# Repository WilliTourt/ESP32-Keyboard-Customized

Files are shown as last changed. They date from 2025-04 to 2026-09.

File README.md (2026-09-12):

# ESP32 Keybrick

> Language: [English](README.md) | [简体中文](readme-zh-CN.md)

A multi-functional ESP32-C3 Bluetooth keyboard named **ESP32 Keybrick**. It provides five customizable mechanical keys and can send keystrokes, key combinations, and media-control commands to computers or other devices that support BLE HID.

This project uses the [Hid2Ble](https://github.com/BearLaboratory/Hid2Ble) library. Thanks to the project for making BLE HID functionality easier to implement.

ESP32 Keybrick internal

ESP32 Keybrick

## Features

- [√] Send a single key
- [√] Send key combinations
- [√] Send media-control keys
- [√] Countdown timer
- [√] Metronome
- [√] Switch between multiple key presets
- [√] Battery monitoring, low-battery notification, and BLE connection status indication
- [-] Create new key presets online without modifying the code
- [-] Automatic reconnection

Seven presets are currently built in:

1. `Ctrl XCVZ`: Ctrl+X, Ctrl+C, Ctrl+V, Ctrl+Z, Ctrl+Shift+Z
2. `Win Combos`: Alt+Tab, Win+D, Ctrl+Alt+Del, Win+Shift+S, empty
3. `VSCode`: Toggle comment, Tab, Shift+Tab, Quick Open, Command Palette
4. `LCEDA Tools`: Wire, Via, Copper, Top Copper, Bottom Copper
5. `SW Drawing`: Line, Circle, Rectangle, Smart Dimension, Normal To
6. `Tabs`: Five Tab keys
7. `MediaCtrls`: Brightness Down, Brightness Up, Volume Down, Volume Up, Play/Pause

To modify the presets, edit `KeyPreset presets[PRESET_COUNT]` in `ESP32-C3 BLE Keybrick/src/sys.cpp`. The code must currently be modified and recompiled; creating entirely new presets online is not supported.

You can refer to the existing presets when editing. For HID key values, consult the HID Usage Tables documentation available online.

You can modify `PRESET_COUNT` to increase or decrease the number of presets. The current number of presets is 7.

## Hardware

Main hardware:

- ESP32-C3-MINI-1 module
- 5 mechanical key switches
- 1 passive buzzer
- 1 status LED
- 0.91-inch 128×32 OLED display
- TP4056 lithium-battery charging module
- 3.7 V lithium battery

Pin definitions:

```cpp
#define ADC_PIN         A0
#define BUZZER_PIN      1
#define BTN_1_PIN       2
#define BTN_2_PIN       3
#define BTN_3_PIN       4
#define BTN_4_PIN       5
#define OLED_SDA        6
#define OLED_SCL        7
#define BTN_5_PIN       8
#define STATUS_LED      10
```

*The key inputs are currently configured as `INPUT` in `KEY_Init()`, so external pull-up resistors are required. If you do not have external pull-up resistors, change the input mode of all five keys to `INPUT_PULLUP` and verify the key-level logic according to your wiring.*

Schematic and PCB:

Schematic

PCB view

PCB view

## Build and Upload

1. Install [PlatformIO](https://platformio.org/) (the PlatformIO extension for VS Code is recommended).
2. Open the `ESP32-C3 BLE Keybrick` folder in PlatformIO.
3. Select the `esp32-c3-devkitm-1` environment.
4. Build and upload the program.

The project uses the Arduino framework. See `ESP32-C3 BLE Keybrick/platformio.ini` for the configuration.

## Usage

The default preset on first startup is `Ctrl XCVZ`:

| Key | Default function |
| --- | --- |
| BTN1 | Ctrl+X |
| BTN2 | Ctrl+C |
| BTN3 | Ctrl+V |
| BTN4 | Ctrl+Z |
| BTN5 | Ctrl+Shift+Z |

The device advertises over BLE as `ESP32C3 BLE Keybrick`. Search for and connect to it in the Bluetooth settings of your computer or other host.

### Mode switching

- Press and hold BTN4 to enter metronome mode.
- Press and hold BTN5 to enter countdown-timer setup mode. Press and hold BTN5 in countdown or any other function mode to return to normal mode.
- Press and hold BTN4 and BTN5 simultaneously to enter preset-selection mode.

### Countdown-timer setup

After entering countdown-timer setup mode:

- BTN1: Adjust hours
- BTN2: Adjust minutes
- BTN3: Enable/start the countdown
- BTN4: Reset
- BTN5: Return to normal mode

### Metronome setup

After entering metronome mode:

- BTN1: Decrease BPM
- BTN2: Increase BPM
- BTN3: Change the time signature
- BTN4: Start/stop the metronome

### Preset selection

After pressing and holding BTN4 and BTN5 simultaneously to enter preset-selection mode:

- BTN1: Select the previous preset
- BTN2: Select the next preset
- BTN3: Confirm and apply the current preset

After confirmation, the current preset is saved to the ESP32's on-chip EEPROM and will still be used after the device is restarted.

## Structure and Resources

- `ESP32-C3 BLE Keybrick/`: PlatformIO source-code folder
- `BOM_ESP32 Keybrick.xlsx`: Bill of materials
- `ESP32 BLE Keyboard v1.2f shell.stl`: Case model
- `ESP32 BLE Keyboard v1.2f cover.stl`: Case cover
- `ESP32-C3 BLE Keyboard v1.2.zip`: GERBER files

## Assembly Notes

- When soldering the OLED, do not insert it all the way. Inserting only part of the pad length is recommended; otherwise, the case and screen may interfere with each other.
- After soldering the mechanical key switches and OLED, cut the pins short to prevent them from protruding. The back of the PCB also needs to accommodate the TP4056 module and lithium battery.
- A 652272 lithium battery is recommended. Its thickness should not exceed approximately 5.5 mm so it can fit in the space between the case and PCB.
- The TP4056 module must be soldered directly to the pad area on the back of the PCB. It is recommended to solder the two pads on the input side first, then hold the module down with tweezers while soldering the remaining four pads.

## Known Issues

- ~~*An extra keystroke is sometimes triggered when returning to normal mode*~~ (fixed)
- ~~*Keys become unavailable when returning to normal mode from metronome mode*~~ (fixed)

## Credits

- Thanks to [BearLaboratory/Hid2Ble](https://github.com/BearLaboratory/Hid2Ble) for the BLE HID library.
- Thanks to WoodBreeze for helping with early testing :)

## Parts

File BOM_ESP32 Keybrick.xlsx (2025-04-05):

ID | Name | Designator | Footprint | Quantity | Manufacturer Part | Manufacturer | Supplier | Supplier Part
1 | Mechanical key shaft | K1,K2,K3,K4,K5 |  | 5
2 | 453K | R3 | R0603 | 1
3 | 100K | R4 | R0603 | 1
4 | 22uF | C1,C2 | C0603 | 2
5 | 2.2uH | L1 | IND-SMD_L3.0-W3.0_FNR30XXS | 1 | FNR3015S2R2MT | cjiang(长江微电) | LCSC | C167747
6 | TLV62568DBVR | U2 | SOT-23-5_L3.0-W1.7-P0.95-LS2.8-BR | 1 | TLV62568DBVR | TI(德州仪器) | LCSC | C163219
7 | ESP32-C3-MINI-1-N4 | U1 | WIFIM-SMD_ESP32-C3-MINI-1 | 1 | ESP32-C3-MINI-1-N4 | ESPRESSIF(乐鑫) | LCSC | C2838502
8 | Key_SMD_3x4x2 | 9,EN | Key_SMD_3x4x2 | 2
9 | 10K | R7,R8,R5,R6,R11,R12,R13,R17,R16 | R0603 | 9
10 | 10uF | C14 | C0603 | 1
11 | 100nF | C15,C17 | C0603 | 2
12 | 1uF | C13,C16 | C0603 | 2
13 | S9013 | Q1 | SOT-23-3_L2.9-W1.4-P1.90-LS2.6-BR | 1 | S9013 | CBI(创基) | LCSC | C2836092
14 | 2.7kHz | BUZ/1 | BUZ-TH_BD9.0-P4.00-D0.6-FD | 1 | QMB-09B-03 | 华能 | LCSC | C96256
15 | 1K | R10 | R0805 | 1
16 | LED_0603-G | LED/10 | LED_0603 | 1
17 | 1K | R9 | R0603 | 1
18 | TP4056模组 | TP4056 | TP4056模组 | 1
19 | 模组-OLED-0.91-12832-I2C-SSD1306 | OLED | MOULD-OLED-0.91-12832-I2C-SSD1306 | 1
20 | 20K | R14 | R0603 | 1
21 | 36K | R15 | R0603 | 1
22 | TA-3525-A1 | SW1 | SW-SMD_3P-L9.1-W3.5-P2.50_BDKG-3P-H2MM | 1 | TA-3525-A1 | Yuandi(元迪) | LCSC | C514018
23 | CH340C | U3 | SOP-16_L10.0-W3.9-P1.27-LS6.0-BL | 1 | CH340C | WCH(南京沁恒) | LCSC | C84681
24 | S8050 | Q3,Q2 | SOT-23-3_L2.9-W1.3-P1.90-LS2.3-BR | 2 | S8050 | 宏迦橙 | LCSC | C20069125
25 | Type-C-TOP_1 | USB1,USB2 | TYPE-C 16PIN-SMD | 2 |  |  | LCSC | C9900005857
26 | USBLC6-2SC6 | D1 | SOT-23-6_L2.9-W1.6-P0.95-LS2.8-BL | 1 | USBLC6-2SC6 | UMW(友台半导体) | LCSC | C2687116
27 | 5.1K | R1,R2,R18,R19 | R0603 | 4

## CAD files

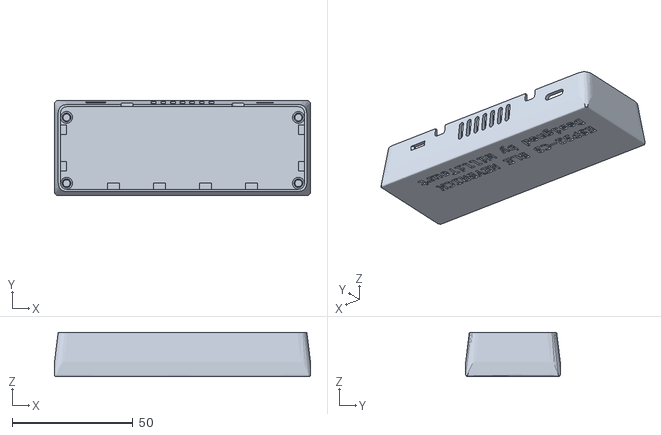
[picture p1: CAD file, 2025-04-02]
ESP32 BLE Keyboard v1.2f shell.stl
106.2 x 39.3 x 18.3

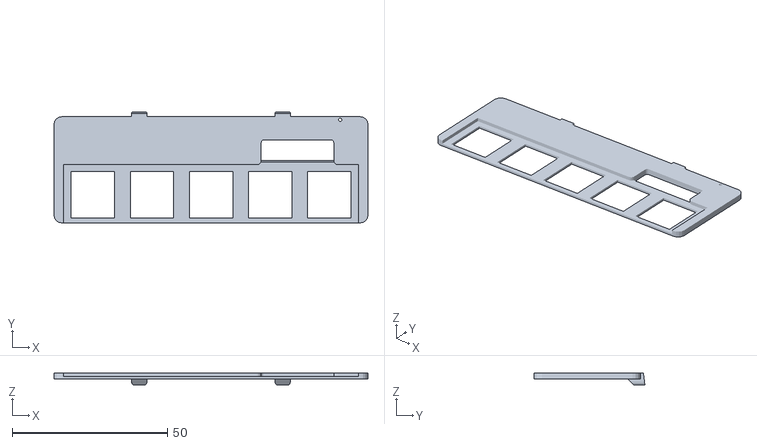
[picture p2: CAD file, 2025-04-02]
ESP32 BLE Keyboard v1.2f cover.stl
101.2 x 35.7 x 4.00

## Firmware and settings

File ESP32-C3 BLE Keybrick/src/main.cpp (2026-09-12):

/*******************************************************
 * ESP32-C3 BLE Keybrick v1.2
 * Copyright (c) 2025 WilliTourt 2944925833@qq.com
 * 
 * CHANGELOG: 
 * - 2025.03 V1.0   Initial release
 * 
 * - 2025.04 V1.1   Display bugfix, changed battery params
 * 
 * - 2026.09 V1.2   Improvements: - MediaCtrl preset now works!
 *                                - fixed display clear problem
 *                                - fixed spurious triggering when new key config enables or quitting alarm or metronome
*******************************************************/

#include <Arduino.h>
#include "Hid2Ble.h"

extern "C" {

#include "key.h"
#include "oled.h"
#include "battery.h"

}

#include "sys.h"
#include "def.h"
#include "timerMetronome.h"

#define SCREEN_ALMOST_TIMEOUT 20000
#define SCREEN_TIMEOUT 30000

void OLED_Update();
void OLED_ChkTimeout();
void KEY_Send();

Hid2Ble keybrick("ESP32C3 BLE Keybrick", "WilliTourt", 100);

/**
  * @brief  Determine whether should send key events to BLE HID device, and count down for timer. 10ms timer interrupt.
  * @param  None
  * @retval None
  */
void IRAM_ATTR KEY_Detect() {

    // Loop through each key to check its state and decide if a key event should be sent
    for (int i = 0; i < 5; i++) {
        if (keyState[i].isReleased) {
            // If the key was released, ensure it is not pressed and set the flag to send a release event
            if (!keyState[i].isPressed) {
                sendRelease = true;
                keyState[i].isReleased = false;
            }
        } else {
            // If the key is pressed, mark it as shouldSend to send the press event later
            if (keyState[i].isPressed) {
                keyState[i].shouldSend = true;
            }
        }
    }

    // Variable for timer count down (each second)
    static uint8_t timerCnt = 0;
    if (timer.enabled) {
        timerCnt++;
        if (timerCnt >= 100) {
            uint32_t now = millis();
            if (now >= (timer.targetSec - 1)) {
                timerTriggered = true;
                timer.enabled = false;
            }
            timerCnt = 0;
        }
    }

}

/**
  * @brief  Update battery level to BLE HID device. 1min timer interrupt.
  * @param  None
  * @retval None
  */
void IRAM_ATTR BLE_UpdateBAT() {
    if (keybrick.isConnected()) {
        keybrick.setBatteryLevel(BAT_GetPercentage());
    }
}

void setup() {

    // Initialize keys, load and apply system preset
    KEY_Init();
    SYS_LoadPreset();
    SYS_ApplyPreset(currentPreset);

    OLED_Init(7, 6, 32, 0);
    pinMode(STATUS_LED, OUTPUT);
    pinMode(BUZZER_PIN, OUTPUT);

    hw_timer_t* timer = timerBegin(0, 80, true);
    timerAttachInterrupt(timer, &KEY_Detect, true);
    timerAlarmWrite(timer, 10000, true);            // 10 ms
    timerAlarmEnable(timer);

    hw_timer_t* timer1 = timerBegin(1, 800, true);
    timerAttachInterrupt(timer1, &BLE_UpdateBAT, true);
    timerAlarmWrite(timer1, 6000000, true);         // 1 min
    timerAlarmEnable(timer1);

    keybrick.begin();
}

void loop() {
    // Update key states and handle mode switching
    active = KEY_Update();

    if (BAT_IS_LOW) {
        OLED_LowBrightness(true);
    }

    SYS_ModeSwitch();

    // Check BLE connection status and send key events if connected
    if (keybrick.isConnected()) {
        sysStatus.bleConnected = true;

        if (enableKey) {
            KEY_Send();
        }
    } else {
        sysStatus.bleConnected = false;
        // How to reconnect automatically?
    }

    // Handle different modes
    switch (currentMode) {  // Clear OLED display and send a release event if mode changed
        case MODE_NORMAL:
            if (!enableKey) { OLED_Clear(); keybrick.send2Ble(release); scrollPos = 0; }
            enableKey = true;
            TIMER_Display();
            break;
        case MODE_TIMER_SET:
            if (enableKey) { OLED_Clear(); keybrick.send2Ble(release); }
            enableKey = false;
            TIMER_Set();
            break;
        case MODE_METRONOME:
            if (enableKey) { OLED_Clear(); keybrick.send2Ble(release); }
            enableKey = false;
            METRONOME_Set();
            break;
        case MODE_KEY_CONFIG:
            if (enableKey) { OLED_Clear(); keybrick.send2Ble(release); scrollPos = 0; }
            enableKey = false;
            SYS_KeyConfig();
            break;
    }

    TIMER_Handle();
    METRONOME_Handle();
    BAT_Read();
    SYS_StatusLEDCtrl();
    OLED_ChkTimeout();
    OLED_Update();
}

/**
  * @brief  Send key events to BLE HID device
  * @param  None
  * @retval None
  */
void KEY_Send() {
    for (int i = 0; i < 5; i++) {
        if (keyState[i].shouldSend && !keyState[i].isReleased) {

            // Key 4/5 are also used for long-press mode switching. Wait until release
            if ((i == 3 || i == 4) && keyState[i].isPressed) {
                continue;
            }

            if (currentPreset == 6) { // MediaCtrls
                keybrick.sendMedia2Ble(media[i]);
            } else {
                switch (i) {
                    case 0: keybrick.send2Ble(k1Buf); break;
                    case 1: keybrick.send2Ble(k2Buf); break;
                    case 2: keybrick.send2Ble(k3Buf); break;
                    case 3: keybrick.send2Ble(k4Buf); break;
                    case 4: keybrick.send2Ble(k5Buf); break;
                }
            }
            keyState[i].isReleased = true;
            keyState[i].shouldSend = false;
        }
    }
    if (sendRelease) {
        if (currentPreset == 6) {
            keybrick.sendMedia2Ble(mediaRelease);
        } else {
            keybrick.send2Ble(release);
        }
        sendRelease = false;
    }
}

// Check if screen timeout has been reached and turn off OLED if necessary
void OLED_ChkTimeout() {
    static uint32_t lastCheck = 0;
    if (active) {
        if (!BAT_IS_LOW) { OLED_LowBrightness(false); }
        lastActivityTime = millis();
        if (!screenOn) {
            OLED_Power(true);
            screenOn = true;
        }
    }
    if (millis() - lastCheck > 1000) {
        if (screenOn && (millis() - lastActivityTime > SCREEN_ALMOST_TIMEOUT)) {
            OLED_LowBrightness(true);
        }
        if (screenOn && (millis() - lastActivityTime > SCREEN_TIMEOUT)) {
            OLED_Power(false);
            screenOn = false;
        }
        lastCheck = millis();
    }
}

// OLED information display & prompts
void OLED_Update() {

    if (!screenOn) { return; }

    switch (currentMode) {
        case MODE_NORMAL:
            OLED_PrintImage(0, 0, 128, 1, (uint8_t*)Title);
            OLED_PrintImage(2, 1, 8, 1, (uint8_t*)BT);
            if (sysStatus.bleConnected) {
                OLED_PrintText(10, 1, "Connected  ", 8);
            } else {
                OLED_PrintText(10, 1, "Unconnected", 8);
            }
            OLED_PrintImage(90, 1, 15, 1, (uint8_t*)Bat);
            OLED_PrintVar(100, 1, BAT_GetPercentage(), "int", 3);
            OLED_PrintText(118, 1, "%", 8);

            static uint32_t lastScroll = 0;
            if (scrollPos < 5) {
                // Padding the line with spaces overwrites the previous text without
                // clearing the display, which avoids visible flicker.
                char keydesc[22];
                snprintf(keydesc, sizeof(keydesc), "Key%d: %s", scrollPos + 1,
                         presets[currentPreset].keyDescription[scrollPos]);
                for (size_t i = strlen(keydesc); i < 21; i++) {
                    keydesc[i] = ' ';
                }
                keydesc[21] = '\0';
                OLED_PrintText(0, 2, keydesc, 8);
            }
            if (millis() - lastScroll > 2000) {
                scrollPos = (scrollPos + 1) % 5;
                lastScroll = millis();
            }
            break;
        case MODE_TIMER_SET:
            OLED_PrintText(0, 0, "> Timer Settings", 8);
            char timeStr[16];
            sprintf(timeStr, " <%02d:%02d>", timer.hours, timer.minutes);
            OLED_PrintText(0, 1, timeStr, 16);
            if (timer.enabled) {
                char timeEn[10];
                uint32_t remainingSec = (timer.targetSec - millis()) / 1000;
                sprintf(timeEn, "%02d:%02d[ON]", remainingSec / 3600, (remainingSec % 3600) / 60);
                OLED_PrintText(72, 1, timeEn, 8);
            } else {
                OLED_ClearPart(72, 1, 128, 2);
            }
            OLED_PrintText(72, 2, "Cnt Down", 8);
            OLED_PrintText(0, 3, "1|HH 2|MM 3|En 4|Rst", 8);
            break;
        case MODE_METRONOME:
            OLED_PrintText(0, 0, "> Metronome", 8);
            char infoStr[32];
            sprintf(infoStr, "BPM:%03d SIG:%d/4", metro.bpm, metro.timeSig);
            OLED_PrintText(0, 1, infoStr, 16);
            OLED_PrintText(0, 3, "1|- 2|+ 3|Sig 4|", 8);
            OLED_PrintText(96, 3, metro.isRunning ? "[RUN]" : "[OFF]", 8);
            break;
        case MODE_KEY_CONFIG:

            static uint32_t lastScroll_cfg = 0;

            OLED_PrintText(0, 0, "> Config Mode", 8);
            if (changeName) {
                OLED_ClearPart(30, 1, 128, 2);
                changeName = false;
            }
            OLED_PrintText(0, 1, " Tag:", 8);
            OLED_PrintText(36, 1, (const char*)presets[currentPreset].name, 8);
            for (int i = 0; i < 2; i++) {
                char line[22];
                if (scrollPos + i < 5) {
                    snprintf(line, sizeof(line), "- Key%d: %s", (scrollPos + i + 1),
                             presets[currentPreset].keyDescription[scrollPos + i]);
                } else {
                    line[0] = '\0';
                }
                // Keep every preview row exactly 21 characters wide. Spaces
                // erase any leftover characters from the previous row.
                for (size_t j = strlen(line); j < 21; j++) {
                    line[j] = ' ';
                }
                line[21] = '\0';
                OLED_PrintText(0, 2 + i, line, 8);
            }
            if (millis() - lastScroll_cfg > 2000) {
                scrollPos = (scrollPos + 1) % 4;
                lastScroll_cfg = millis();
            }

            char presetInfo[8];
            sprintf(presetInfo, "[%d/%d]", currentPreset + 1, PRESET_COUNT);
            OLED_PrintText(96, 0, presetInfo, 8);
            break;
    }

}

// If timer is enabled, display remaining time on OLED
void TIMER_Display() {
    if(timer.enabled) {
        char timeStr[32];
        uint32_t remainingSec = (timer.targetSec - millis()) / 1000;
        sprintf(timeStr, "TIM remaining: %02d:%02d", remainingSec / 3600, (remainingSec % 3600) / 60);
        OLED_PrintText(0, 3, timeStr, 8);
    } else {
        OLED_ClearPart(0, 3, 128, 4);
    }
}

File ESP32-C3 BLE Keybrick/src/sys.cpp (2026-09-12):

#include "sys.h"
#include <Preferences.h>

SystemMode currentMode = MODE_NORMAL;

struct SystemStatus sysStatus = {
    .bleConnected = false,
    .lastLedUpdate = 0
};



/*
Byte 0 Modifiers
    0x01: Left Ctrl
    0x02: Left Shift
    0x04: Left Alt
    0x08: Left GUI (Win/Cmd)
    0x10: Right Ctrl
    0x20: Right Shift
    0x40: Right Alt 
    0x80: Right GUI

Byte 1 Reserved

Byte 2 Key 1
Byte 3 Key 2
Byte 4 Key 3
Byte 5 Key 4
Byte 6 Key 5
Byte 7 Key 6
*/
KeyPreset presets[PRESET_COUNT] = {
    {
        {
            { 0x01, 0x00, 0x1B, 0x00, 0x00, 0x00, 0x00, 0x00 }, // Ctrl+X
            { 0x01, 0x00, 0x06, 0x00, 0x00, 0x00, 0x00, 0x00 }, // Ctrl+C
            { 0x01, 0x00, 0x19, 0x00, 0x00, 0x00, 0x00, 0x00 }, // Ctrl+V
            { 0x01, 0x00, 0x1D, 0x00, 0x00, 0x00, 0x00, 0x00 }, // Ctrl+Z
            { 0x03, 0x00, 0x1D, 0x00, 0x00, 0x00, 0x00, 0x00 }  // Ctrl+Shift+Z
        },
        "Ctrl XCVZ",
        { "Ctrl+X", "Ctrl+C", "Ctrl+V", "Ctrl+Z", "Ctrl+Shift+Z" }
    },
    {
        {
            { 0x04, 0x00, 0x2B, 0x00, 0x00, 0x00, 0x00, 0x00 }, // Alt+Tab
            { 0x08, 0x00, 0x07, 0x00, 0x00, 0x00, 0x00, 0x00 }, // Win+D
            { 0x05, 0x00, 0x4C, 0x00, 0x00, 0x00, 0x00, 0x00 }, // Ctrl+Alt+Del
            { 0x0A, 0x00, 0x16, 0x00, 0x00, 0x00, 0x00, 0x00 }, // Win+Shift+S
            { 0x00 }                                            // Empty
        },
        "Win Combos",
        { "Alt+Tab", "Win+D", "Ctrl+Alt+Del", "N/A", "N/A" }
    },
    {
        {
            { 0x01, 0x00, 0x38, 0x00, 0x00, 0x00, 0x00, 0x00 }, // Ctrl+/
            { 0x00, 0x00, 0x2B, 0x00, 0x00, 0x00, 0x00, 0x00 }, // Tab
            { 0x02, 0x00, 0x2B, 0x00, 0x00, 0x00, 0x00, 0x00 }, // Shift+Tab
            { 0x01, 0x00, 0x13, 0x00, 0x00, 0x00, 0x00, 0x00 }, // Ctrl+P
            { 0x03, 0x00, 0x13, 0x00, 0x00, 0x00, 0x00, 0x00 }  // Ctrl+Shift+P
        },
        "VSCode",
        { "Comment", "Tab", "Shift+Tab", "Quick Open", "Command Palette" }
    },
    {
        {
            
            { 0x04, 0x00, 0x1A, 0x00, 0x00, 0x00, 0x00, 0x00 }, // Alt+W
            { 0x04, 0x00, 0x19, 0x00, 0x00, 0x00, 0x00, 0x00 }, // Alt+V
            { 0x04, 0x00, 0x08, 0x00, 0x00, 0x00, 0x00, 0x00 }, // Alt+E
            { 0x02, 0x00, 0x55, 0x00, 0x00, 0x00, 0x00, 0x00 }, // Shift+Num*
            { 0x00, 0x00, 0x55, 0x00, 0x00, 0x00, 0x00, 0x00 }  // Num*
        },
        "LCEDA Tools",
        { "Alt+W(Wire)", "Alt+V(Via)", "Alt+E(Copper)", "Upper Copper", "Lower Copper" }
    },
    {
        {
            { 0x00, 0x00, 0x0F, 0x00, 0x00, 0x00, 0x00, 0x00 }, // L
            { 0x00, 0x00, 0x06, 0x00, 0x00, 0x00, 0x00, 0x00 }, // C
            { 0x00, 0x00, 0x15, 0x00, 0x00, 0x00, 0x00, 0x00 }, // R
            { 0x00, 0x00, 0x16, 0x00, 0x00, 0x00, 0x00, 0x00 }, // S
            { 0x01, 0x00, 0x25, 0x00, 0x00, 0x00, 0x00, 0x00 }  // Ctrl+8
        },
        "SW Drawing",
        { "Line", "Circle", "Rectangle", "Smart Dim", "Normal to" }
    },
    {
        {
            
            { 0x00, 0x00, 0x2B, 0x00, 0x00, 0x00, 0x00, 0x00 }, // Tab
            { 0x00, 0x00, 0x2B, 0x00, 0x00, 0x00, 0x00, 0x00 },
            { 0x00, 0x00, 0x2B, 0x00, 0x00, 0x00, 0x00, 0x00 },
            { 0x00, 0x00, 0x2B, 0x00, 0x00, 0x00, 0x00, 0x00 },
            { 0x00, 0x00, 0x2B, 0x00, 0x00, 0x00, 0x00, 0x00 }
        },
        "Tabs",
        { "Tab", "Tab", "Tab", "Tab", "Tab" }
    },

/*************************************************************************************************************/
    {
        {
            { 0x00 }, // Media report is sent separately (currentPreset == 6)
            { 0x00 },
            { 0x00 },
            { 0x00 },
            { 0x00 },
        },
        "MediaCtrls",
        { "Brightness -", "Brightness +", "Volume -", "Volume +", "Play/Pause" }
    }
};

char media[5][2] { // Consumer-control report bit masks
    { 0x00, 0x01 }, // Brightness Down
    { 0x80, 0x00 }, // Brightness Up
    { 0x40, 0x00 }, // Volume Down
    { 0x20, 0x00 }, // Volume Up
    { 0x08, 0x00 }  // Play/Pause
};

char mediaRelease[2] { 0x00, 0x00 };

uint8_t currentPreset = 0;
uint8_t scrollPos = 0;
bool changeName = false;

uint32_t lastActivityTime = 0;
bool screenOn = true;
bool active = false;

/**
  * @brief  Switches the system mode based on the key presses.
  * @param  None
  * @retval None
  */
void SYS_ModeSwitch() {
    if (k5LongPressed && !keyState[3].isPressed) {
        // Suppress the pending normal key event for key 5. It was held for
        // mode switching and must not be sent after the key is released.
        keyState[4].shouldSend = false;
        keyState[4].isReleased = true;
        if (currentMode == MODE_NORMAL) {
            currentMode = MODE_TIMER_SET;
        } else if ( (currentMode == MODE_TIMER_SET) ||
                    (currentMode == MODE_METRONOME) ||
                    (currentMode == MODE_KEY_CONFIG) ) {
            currentMode = MODE_NORMAL;
        }
        k5LongPressed = false;
        k5PressStartTime = 0;
    } else if (k4LongPressed && !keyState[4].isPressed) {
        // Suppress the pending normal key event for key 4.
        keyState[3].shouldSend = false;
        keyState[3].isReleased = true;
        if (currentMode == MODE_NORMAL) {
            currentMode = MODE_METRONOME;
        };
        k4LongPressed = false;
        k4PressStartTime = 0;
    }
    if (k4LongPressed && k5LongPressed) {
        // Suppress both normal key events when entering key configuration.
        keyState[3].shouldSend = false;
        keyState[3].isReleased = true;
        keyState[4].shouldSend = false;
        keyState[4].isReleased = true;
        currentMode = MODE_KEY_CONFIG;
        k4LongPressed = false;
        k5LongPressed = false;
        k4PressStartTime = 0;
        k5PressStartTime = 0;
    }
}

/**
  * @brief  Change key configuration & key mapping.
  * @param  None
  * @retval None
  */
 void SYS_KeyConfig() {
    // static uint8_t selectedOption = 0; // 0: Load, 1: New

    if ( keyState[0].isPressed ) {
        currentPreset = (currentPreset + PRESET_COUNT - 1) % PRESET_COUNT;
        scrollPos = 0;
        changeName = true;
        delay(100);
    }
    
    if ( keyState[1].isPressed ) {
        currentPreset = (currentPreset + 1) % PRESET_COUNT;
        changeName = true;
        scrollPos = 0;
        delay(100);
    }
    
    if( keyState[2].isPressed ) {
        SYS_ConfirmPreset(currentPreset);
        SYS_ApplyPreset(currentPreset);
        // The confirm key must not become a normal key press when we leave
        // config mode. Keep it suppressed until the physical key is released.
        keyState[2].shouldSend = false;
        keyState[2].isReleased = true;
        delay(500);
        currentMode = MODE_NORMAL;
    }
}


void SYS_SavePreset() {

}
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

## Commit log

2025-03-28 Shell 3D Model
    [ESP32 BLE Keyboard v1.2f.stl]
2025-03-28 PCB Gerber
2025-04-02 Shell 3D Models
    [ESP32 BLE Keyboard v1.2f cover.stl, ESP32 BLE Keyboard v1.2f shell.stl]
2026-09-12 improvements!
    - mediactrl now works!!!
    - fixed display clear problem
    - fixed spurious triggering when new key config enables or quitting alarm or metronome
    [main.cpp, sys.cpp]
